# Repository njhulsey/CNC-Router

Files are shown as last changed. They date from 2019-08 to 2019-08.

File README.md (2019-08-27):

# CNC-Router
CNC Router based off of the A4988 and ATmega2560

This board used the ATmega2560 to control 3 steppers, 4 servos, and manage 3 switches! Quite a lot to it! It also has a flex cable for an interface board to provide more user interaction. The board will an Oled, potentiometers and buttons. There's a barrel jack connector for the steppers power and an ftdi chip for serial communication. Got these made from PCBway. Been really happy with the finishes and the prices are pretty unbeatable.

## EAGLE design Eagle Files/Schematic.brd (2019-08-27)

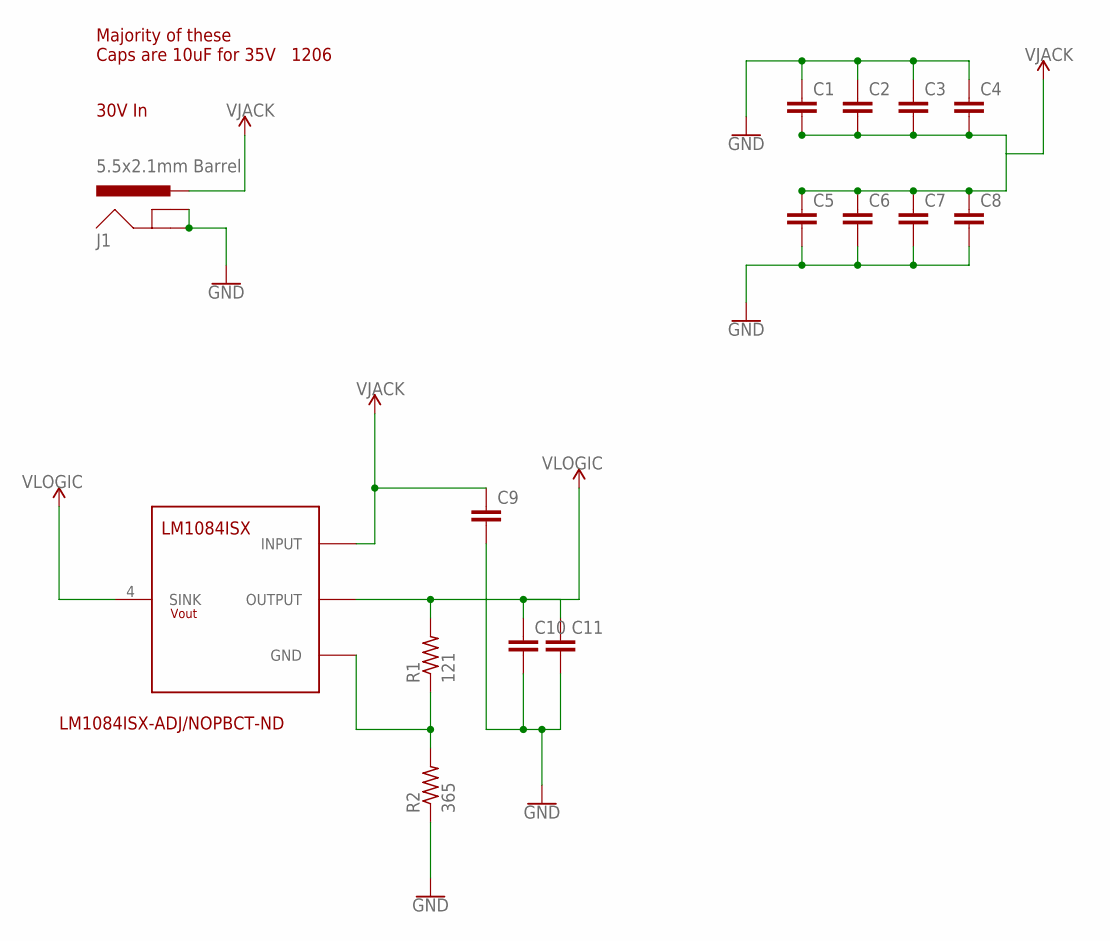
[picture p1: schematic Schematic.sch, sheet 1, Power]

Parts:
C1, C2, C3, C4, C5, C6, C7, C8, C9, C10, C11: C-EUC1206K; C1206K
J1: 5.5x2.1mm Barrel; POWER_JACK_SMD
R1: 121; R0805
R2: 365; R0805
U$2: LM1084ISX; TO254P1435X464-4N

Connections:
GND: C1.1, C2.1, C3.1, C4.1, C5.2, C6.2, C7.2, C8.2, C9.2, C10.2, C11.2, J1.GND (GNDBREAK), J1.P$4 (GND), R2.1; also elsewhere on the board
unnamed: R1.1, R2.2, U$2.1 (GND)
VJACK: C1.2, C2.2, C3.2, C4.2, C5.1, C6.1, C7.1, C8.1, C9.1, J1.VIN0 (PWR), U$2.3 (INPUT); also elsewhere on the board
VLOGIC: C10.1, C11.1, R1.2, U$2.2 (OUTPUT), U$2.4 (SINK); also elsewhere on the board

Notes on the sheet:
30V In
Majority of these Caps are 10uF for 35V
LM1084ISX-ADJ/NOPBCT-ND
1206

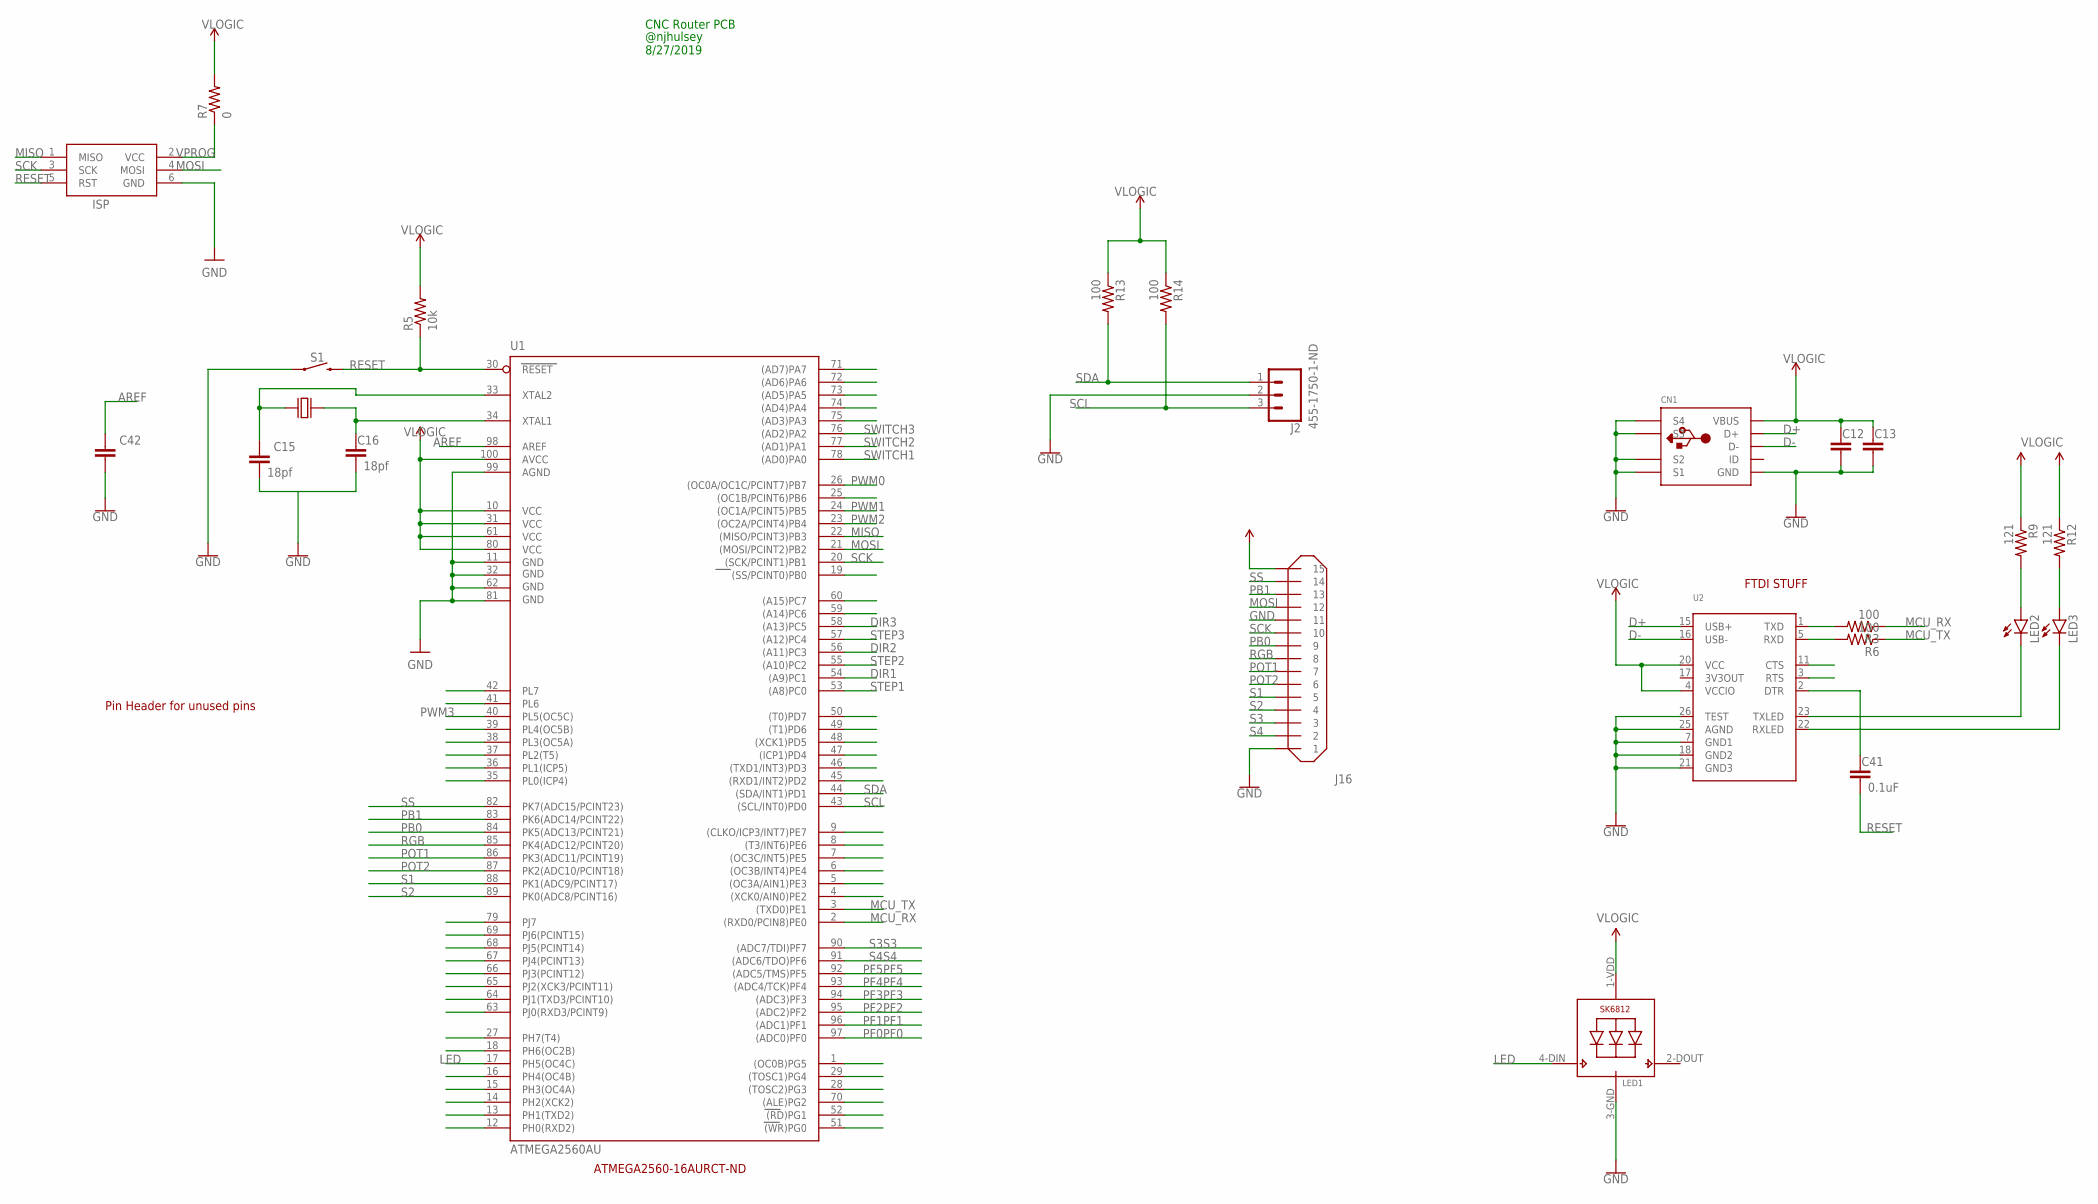
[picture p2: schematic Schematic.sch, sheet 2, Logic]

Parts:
C12, C13, C42: C-EUC0805; C0805
C15, C16: 18pf; C0805
C41: 0.1uF; C0805
CN1: USBMINIBLARGE; USB-MINIB_LARGER
ISP: AVRISP-6; AVRISP
J2: 455-1750-1-ND; 1X03
J16: MOLEX-15-FFC-VERT; MOLEX-VERT-FFC-15
LED1: SK6812_5050; LED5050
LED2, LED3: LEDCHIPLED_0805; CHIPLED_0805
R3, R6, R13, R14: 100; R0805
R5: 10k; R0805
R7: 0; R0805
R9, R12: 121; R0805
S1: MOMENTARY-SWITCH-SPST-SMD-5.2-REDUNDANT; TACTILE_SWITCH_SMD_5.2MM
U1: ATMEGA2560AU; TQFP100
U2: FT232RLSSOP28; SSOP28DB
U$1: CRYSTAL-SMD-HC-49US; CRYSTAL_SMD_HC-49/US

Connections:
3V3OUT: U2.17 (3V3OUT)
AREF: C42.1, U1.98 (AREF)
D+: CN1.D+, U2.15 (USB+)
D-: CN1.D-, U2.16 (USB-)
DIR1: U1.54 ((A9)PC1); also elsewhere on the board
DIR2: U1.56 ((A11)PC3); also elsewhere on the board
DIR3: U1.58 ((A13)PC5); also elsewhere on the board
GND: C12.2, C13.2, C15.2, C16.2, C42.2, CN1.GND, CN1.GND1 (S1), CN1.GND2 (S2), CN1.GND3 (S3), CN1.GND4 (S4), ISP.6 (GND), J2.2, J16.P$1 (1), J16.P$2 (1), J16.P$21 (11), J16.P$22 (11), LED1.3-GND (GND), S1.1, S1.2 (1), U1.11 (GND), U1.32 (GND1), U1.62 (GND2), U1.81 (GND3), U1.99 (AGND), U2.7 (GND1), U2.18 (GND2), U2.21 (GND3), U2.25 (AGND), U2.26 (TEST); also elsewhere on the board
LED: LED1.4-DIN (DI), U1.17 (PH5(OC4C))
MCU_RX: R3.1, U1.2 ((RXD0/PCIN8)PE0)
MCU_TX: R6.1, U1.3 ((TXD0)PE1)
MISO: ISP.1 (MISO), U1.22 ((MISO/PCINT3)PB3)
MOSI: ISP.4 (MOSI), J16.P$23 (12), J16.P$24 (12), U1.21 ((MOSI/PCINT2)PB2)
unnamed: LED2.A, R9.2
unnamed: LED3.A, R12.2
unnamed: R3.2, U2.1 (TXD)
unnamed: R6.2, U2.5 (RXD)
unnamed: C41.1, U2.2 (DTR)
unnamed: LED2.C, U2.23 (TXLED)
unnamed: LED3.C, U2.22 (RXLED)
unnamed: C15.1, U1.33 (XTAL2), U$1.P$2
unnamed: C16.1, U1.34 (XTAL1), U$1.P$1
PB0: J16.P$17 (9), J16.P$18 (9), U1.84 (PK5(ADC13/PCINT21))
PB1: J16.P$25 (13), J16.P$26 (13), U1.83 (PK6(ADC14/PCINT22))
PF0: U1.97 ((ADC0)PF0)
PF1: U1.96 ((ADC1)PF1)
PF2: U1.95 ((ADC2)PF2)
PF3: U1.94 ((ADC3)PF3)
PF4: U1.93 ((ADC4/TCK)PF4)
PF5: U1.92 ((ADC5/TMS)PF5)
POT1: J16.P$13 (7), J16.P$14 (7), U1.86 (PK3(ADC11/PCINT19))
POT2: J16.P$11 (6), J16.P$12 (6), U1.87 (PK2(ADC10/PCINT18))
PWM0: U1.26 ((OC0A/OC1C/PCINT7)PB7); also elsewhere on the board
PWM1: U1.24 ((OC1A/PCINT5)PB5); also elsewhere on the board
PWM2: U1.23 ((OC2A/PCINT4)PB4); also elsewhere on the board
PWM3: U1.40 (PL5(OC5C)); also elsewhere on the board
RESET: C41.2, ISP.5 (RST), R5.1, S1.3 (2), S1.4 (2), U1.30 (RESET)
RGB: J16.P$15 (8), J16.P$16 (8), U1.85 (PK4(ADC12/PCINT20))
S1: J16.P$9 (5), J16.P$10 (5), U1.88 (PK1(ADC9/PCINT17))
S2: J16.P$7 (4), J16.P$8 (4), U1.89 (PK0(ADC8/PCINT16))
S3: J16.P$5 (3), J16.P$6 (3), U1.90 ((ADC7/TDI)PF7)
S4: J16.P$3 (2), J16.P$4 (2), U1.91 ((ADC6/TDO)PF6)
SCK: ISP.3 (SCK), J16.P$19 (10), J16.P$20 (10), U1.20 ((SCK/PCINT1)PB1)
SCL: J2.3, R14.2, U1.43 ((SCL/INT0)PD0)
SDA: J2.1, R13.2, U1.44 ((SDA/INT1)PD1)
SS: J16.P$27 (14), J16.P$28 (14), U1.82 (PK7(ADC15/PCINT23))
STEP1: U1.53 ((A8)PC0); also elsewhere on the board
STEP2: U1.55 ((A10)PC2); also elsewhere on the board
STEP3: U1.57 ((A12)PC4); also elsewhere on the board
SWITCH1: U1.78 ((AD0)PA0); also elsewhere on the board
SWITCH2: U1.77 ((AD1)PA1); also elsewhere on the board
SWITCH3: U1.76 ((AD2)PA2); also elsewhere on the board
VCC: J16.P$29 (15), J16.P$30 (15)
VLOGIC: C12.1, C13.1, CN1.VBUS, LED1.1-VDD (VDD), R5.2, R7.2, R9.1, R12.1, R13.1, R14.1, U1.10 (VCC), U1.31 (VCC1), U1.61 (VCC2), U1.80 (VCC3), U1.100 (AVCC), U2.4 (VCCIO), U2.20 (VCC); also elsewhere on the board
VPROG: ISP.2 (VCC), R7.1

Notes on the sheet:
ATMEGA2560-16AURCT-ND
FTDI STUFF
Pin Header for unused pins
@njhulsey 8/27/2019
CNC Router PCB

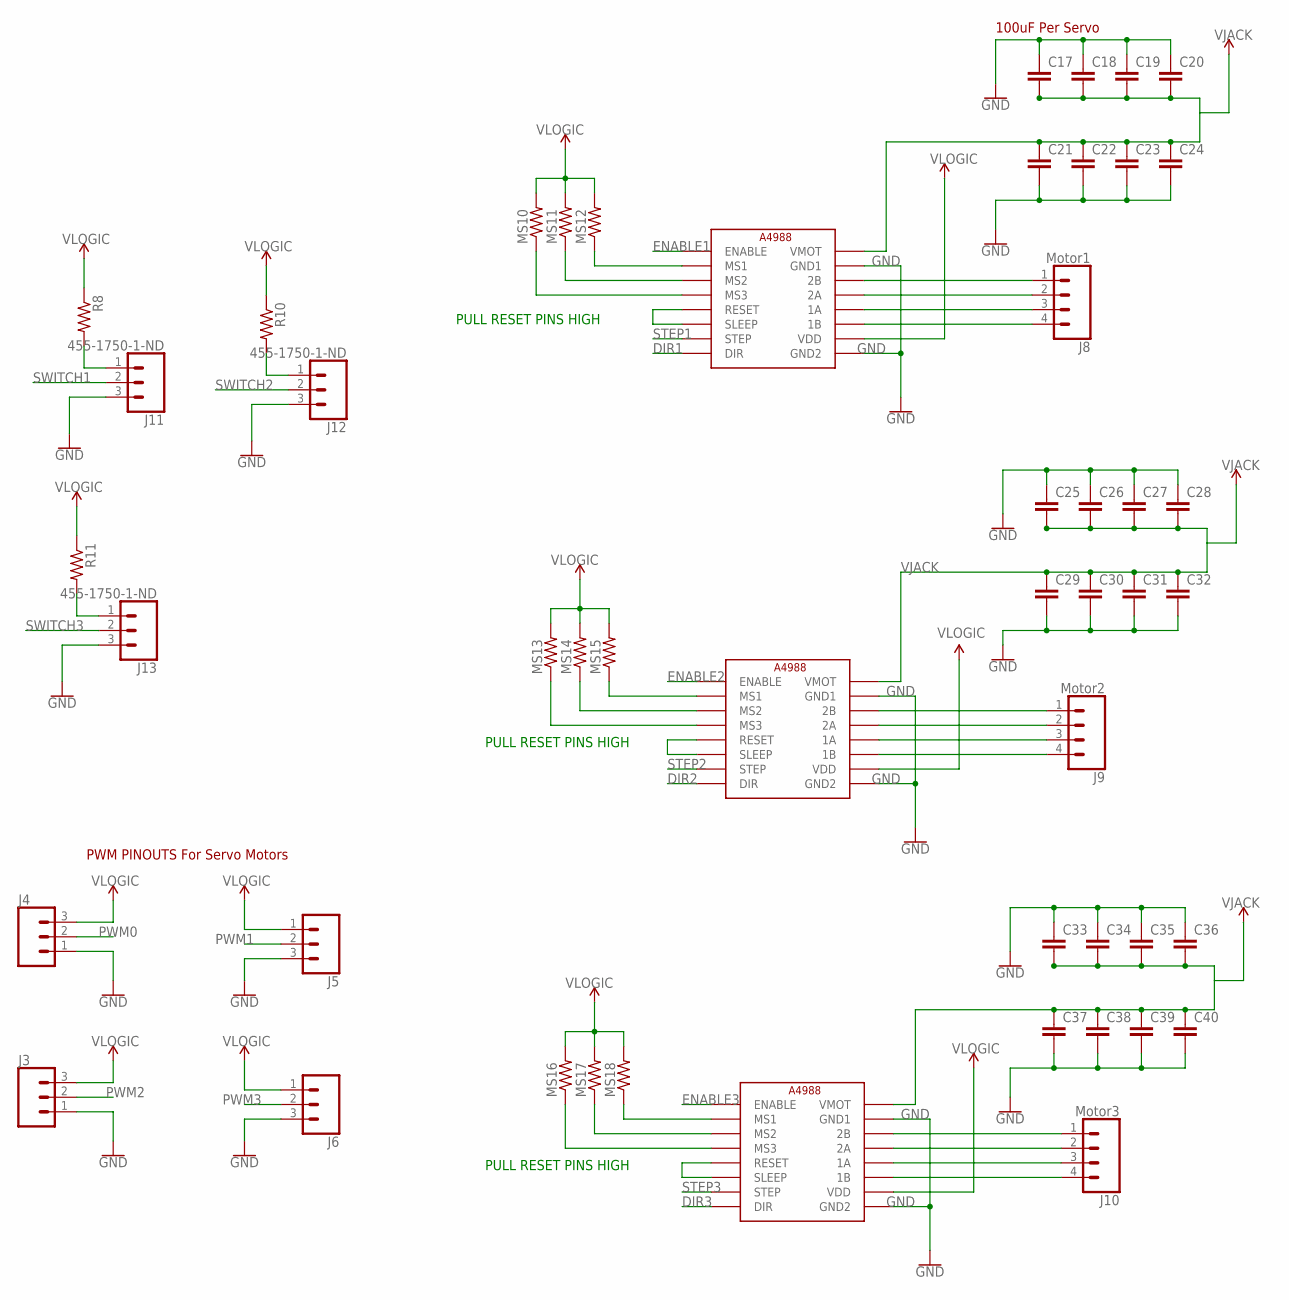
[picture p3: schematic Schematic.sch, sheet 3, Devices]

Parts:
C17, C18, C19, C20, C21, C22, C23, C24, C25, C26, C27, C28, C29, C30, C31, C32, C33, C34, C35, C36, C37, C38, C39, C40: C-EUC1206K; C1206K
DRVER_4, DRVER_5, DRVER_6: Driver1; A4988
J3, J4, J5, J6, J11, J12, J13: 455-1750-1-ND; 1X03
J8: Motor1; 1X04
J9: Motor2; 1X04
J10: Motor3; 1X04
MS10, MS11, MS12, MS13, MS14, MS15, MS16, MS17, MS18: R-US_R0805; R0805
R8, R10, R11: R-US_R0805; R0805

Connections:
DIR1: DRVER_4.P$9 (DIR); also elsewhere on the board
DIR2: DRVER_5.P$9 (DIR); also elsewhere on the board
DIR3: DRVER_6.P$9 (DIR); also elsewhere on the board
ENABLE1: DRVER_4.P$16 (ENABLE)
ENABLE2: DRVER_5.P$16 (ENABLE)
ENABLE3: DRVER_6.P$16 (ENABLE)
GND: C17.1, C18.1, C19.1, C20.1, C21.2, C22.2, C23.2, C24.2, C25.1, C26.1, C27.1, C28.1, C29.2, C30.2, C31.2, C32.2, C33.1, C34.1, C35.1, C36.1, C37.2, C38.2, C39.2, C40.2, DRVER_4.P$1 (GND2), DRVER_4.P$7 (GND1), DRVER_5.P$1 (GND2), DRVER_5.P$7 (GND1), DRVER_6.P$1 (GND2), DRVER_6.P$7 (GND1), J3.1, J4.1, J5.3, J6.3, J11.3, J12.3, J13.3; also elsewhere on the board
unnamed: J11.1, R8.2
unnamed: J12.1, R10.2
unnamed: J13.1, R11.2
unnamed: DRVER_4.P$13 (MS3), MS10.1
unnamed: DRVER_4.P$14 (MS2), MS11.1
unnamed: DRVER_4.P$15 (MS1), MS12.1
unnamed: DRVER_4.P$3 (1B), J8.4
unnamed: DRVER_4.P$4 (1A), J8.3
unnamed: DRVER_4.P$5 (2A), J8.2
unnamed: DRVER_4.P$6 (2B), J8.1
unnamed: DRVER_6.P$13 (MS3), MS16.1
unnamed: DRVER_6.P$14 (MS2), MS17.1
unnamed: DRVER_6.P$15 (MS1), MS18.1
unnamed: DRVER_6.P$6 (2B), J10.1
unnamed: DRVER_6.P$5 (2A), J10.2
unnamed: DRVER_6.P$4 (1A), J10.3
unnamed: DRVER_6.P$3 (1B), J10.4
unnamed: DRVER_5.P$15 (MS1), MS15.1
unnamed: DRVER_5.P$14 (MS2), MS14.1
unnamed: DRVER_5.P$13 (MS3), MS13.1
unnamed: DRVER_5.P$6 (2B), J9.1
unnamed: DRVER_5.P$5 (2A), J9.2
unnamed: DRVER_5.P$4 (1A), J9.3
unnamed: DRVER_5.P$3 (1B), J9.4
PWM0: J4.2; also elsewhere on the board
PWM1: J5.2; also elsewhere on the board
PWM2: J3.2; also elsewhere on the board
PWM3: J6.2; also elsewhere on the board
SLEEP3: DRVER_4.P$11 (SLEEP), DRVER_4.P$12 (RESET)
SLEEP4: DRVER_5.P$11 (SLEEP), DRVER_5.P$12 (RESET)
SLEEP5: DRVER_6.P$11 (SLEEP), DRVER_6.P$12 (RESET)
STEP1: DRVER_4.P$10 (STEP); also elsewhere on the board
STEP2: DRVER_5.P$10 (STEP); also elsewhere on the board
STEP3: DRVER_6.P$10 (STEP); also elsewhere on the board
SWITCH1: J11.2; also elsewhere on the board
SWITCH2: J12.2; also elsewhere on the board
SWITCH3: J13.2; also elsewhere on the board
VJACK: C17.2, C18.2, C19.2, C20.2, C21.1, C22.1, C23.1, C24.1, C25.2, C26.2, C27.2, C28.2, C29.1, C30.1, C31.1, C32.1, C33.2, C34.2, C35.2, C36.2, C37.1, C38.1, C39.1, C40.1, DRVER_4.P$8 (VMOT), DRVER_5.P$8 (VMOT), DRVER_6.P$8 (VMOT); also elsewhere on the board
VLOGIC: DRVER_4.P$2 (VDD), DRVER_5.P$2 (VDD), DRVER_6.P$2 (VDD), J3.3, J4.3, J5.1, J6.1, MS10.2, MS11.2, MS12.2, MS13.2, MS14.2, MS15.2, MS16.2, MS17.2, MS18.2, R8.1, R10.1, R11.1; also elsewhere on the board

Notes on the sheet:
100uF Per Servo
PWM PINOUTS For Servo Motors
PULL RESET PINS HIGH

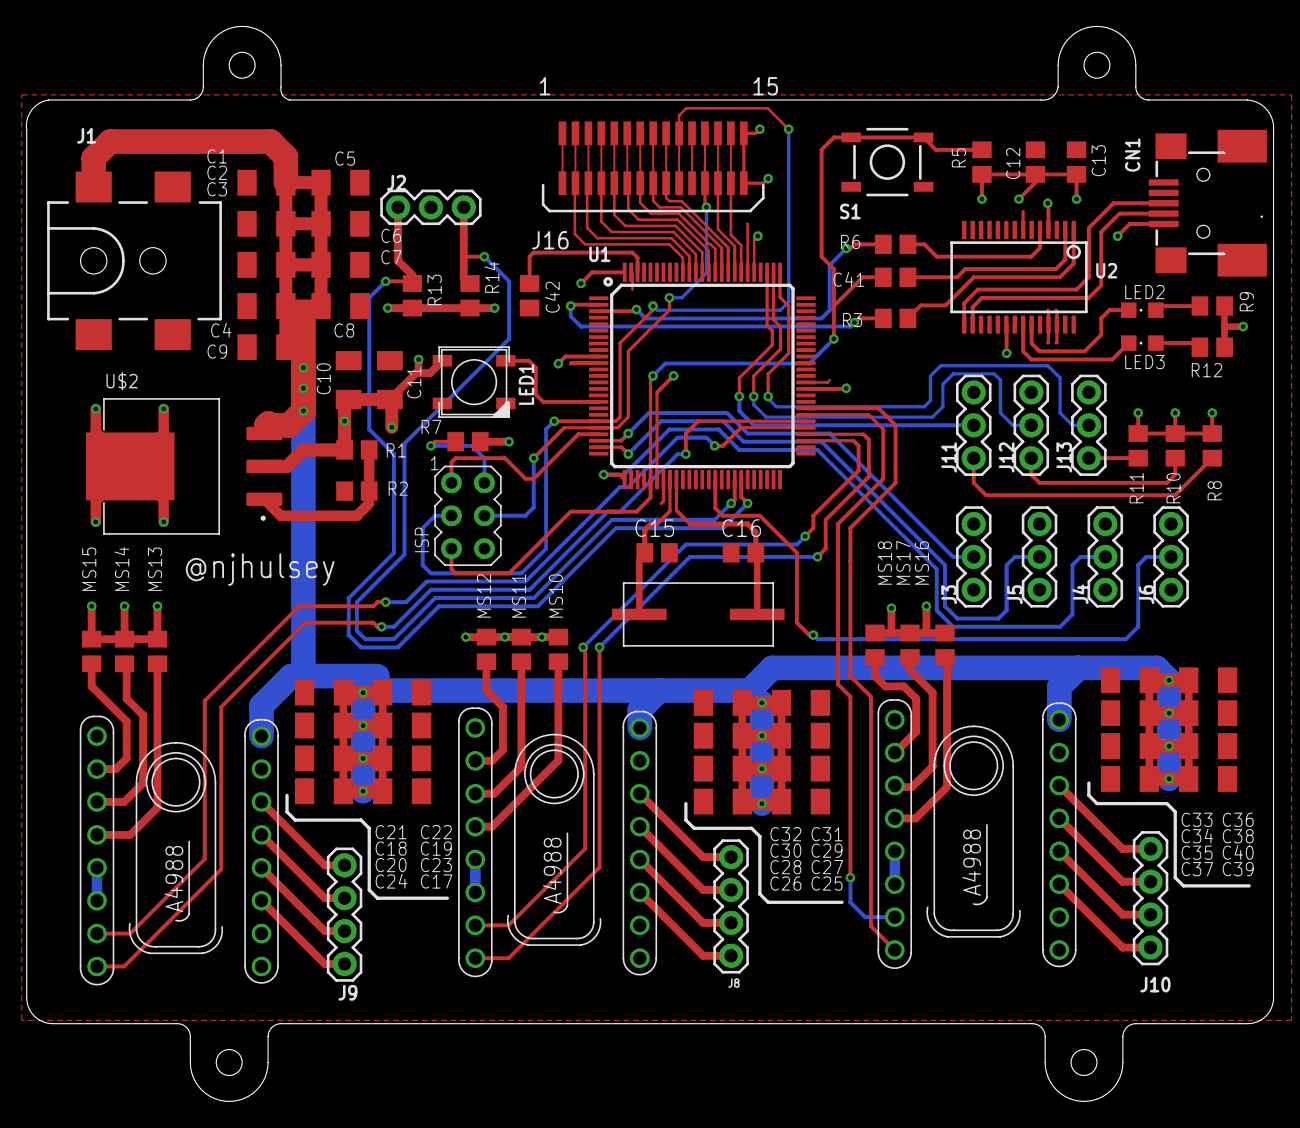
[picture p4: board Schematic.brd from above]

Board: 2 copper layers, 96.3 x 83.0 mm, 89 parts (0 on the bottom side), 77 nets.

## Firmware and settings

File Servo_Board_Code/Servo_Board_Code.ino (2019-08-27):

/**
 * This is simple test code for my CNC Router PCB
 * You can find out more at www.github.com/njhulsey
 * 
 * 
 * Nick Hulsey (@njhulsey)
 * 8/27/2019
 */


#include <Adafruit_NeoPixel.h>

#define DIR1                 36
#define STEP1                37

#define DIR2                 34
#define STEP2                35

#define DIR3                 32
#define STEP3                33

#define NEO_PIXEL_PIN        8 
Adafruit_NeoPixel pixels(1, NEO_PIXEL_PIN, NEO_GRB + NEO_KHZ800);

void setup() {

  pixels.begin(); // INITIALIZE NeoPixel strip object (REQUIRED)
  pixels.setBrightness(20);
  ledColor(0xFF00BF);

  Serial.begin(115200);
  ledColor(0x00DFBF);
  

  pinMode(DIR1,OUTPUT);
  pinMode(STEP1,OUTPUT);

  pinMode(DIR2,OUTPUT);
  pinMode(STEP2,OUTPUT);
  
  pinMode(DIR3,OUTPUT);
  pinMode(STEP3,OUTPUT);


}

void loop() {

  delay(1000);
  Serial.write("Turning motor 1 for 500 millisec\n");
 
  digitalWrite(DIR1,HIGH); // Enables the motor to move in a particular direction
  digitalWrite(DIR2,LOW);
  // Makes 200 pulses for making one full cycle rotation
  for(int x = 0; x < 800; x++) {
    digitalWrite(STEP1,HIGH); 
    digitalWrite(STEP2,HIGH);
    delayMicroseconds(500); 
    digitalWrite(STEP1,LOW); 
    digitalWrite(STEP2,LOW);
    delayMicroseconds(500); 
  }
  delay(1000); // One second delay
  
}


void ledColor(uint32_t color){
  pixels.setPixelColor(0, color);
  pixels.show();   // Send the updated pixel colors to the hardware.
}

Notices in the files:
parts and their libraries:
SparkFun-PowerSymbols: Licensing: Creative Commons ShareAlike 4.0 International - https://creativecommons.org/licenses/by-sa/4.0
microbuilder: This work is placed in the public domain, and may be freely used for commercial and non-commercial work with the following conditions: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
